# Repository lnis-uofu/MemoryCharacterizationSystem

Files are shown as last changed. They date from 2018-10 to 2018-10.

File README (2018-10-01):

 ¸,ø¤º°`°º¤ø,¸¸,ø¤º°  LNIS at University of Utah  °º¤ø,¸¸,ø¤º°`°º¤ø,¸
                   Prof. Pierre-Emmanuel Gaillardon
                  pierre-emmanuel.gaillardon@utah.edu

*--------------------------------------------------------------------------
* Memory Characterization System Development Package README
*--------------------------------------------------------------------------

* Readme File Author : Armando Biscontini
* Created On 	       : September 8, 2016
* Last Modified On   : September 8, 2016
* Description	       : This file describes the  directory structure
*                      of the MCS Development Package
*--------------------------------------------------------------------------

*** Disclaimer

This program is free software. It comes without any warranty, to
the extent permitted by applicable law. You can redistribute it
and/or modify it under the terms of the GNU Lesser General Public License, Version 3.
See https://www.gnu.org/licenses/lgpl-3.0.txt for more details.

If you use any of the material that comes along with this package, please refer to the
following paper for citation purpose:

A. Biscontini, M. Thammasack, G. De Micheli and P.-E. Gaillardon,
"An FPGA-Based Test System for RRAM Technology Characterization"

*** MCS Dev Package Directory Structure

▾ MCS_dev_package/

  ▾  PCB/						    : Contains the files regarding the MCS printed circuit board design.
    
    ▸ Datasheets/ 			: Folder containing the datasheets of the component that are mounted on the PCB.
    
    ▸ ReRAM Libraries/  : Altium design libraries necessary for a complete dasgn of the MCS. 
    
    ▸ ReRAM_Board_3/    : Altium design project folder.
  
  ▾ chip_and_custom_socket_3DCAD/

    ▸ LSI-PLLGA100_0.9.4/        : Folder containing the SolidWorks CAD files of the of the chip.

    ▸ LPF100-0691-15AB55L.PDF    : CAD drawing of the custom socket.

  ▾ chip_cadence_files       : Folder that holds all the Cadence design files of the chip.

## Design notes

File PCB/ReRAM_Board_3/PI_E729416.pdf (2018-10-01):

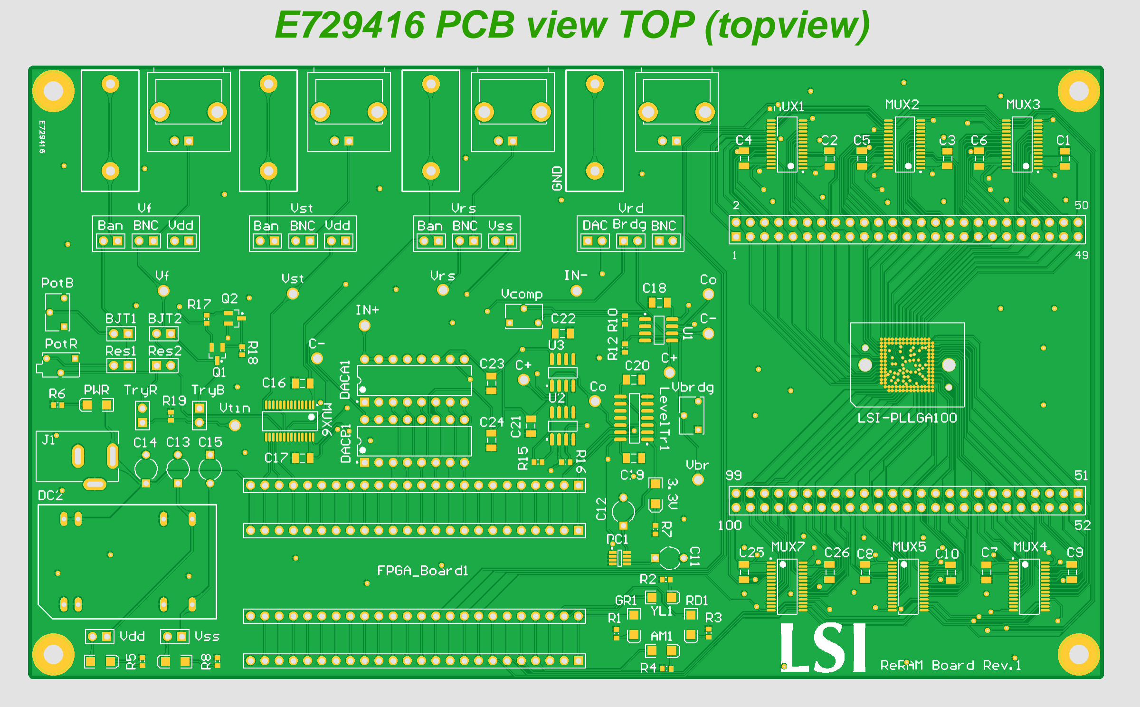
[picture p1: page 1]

E729416 PCB view TOP (topview)

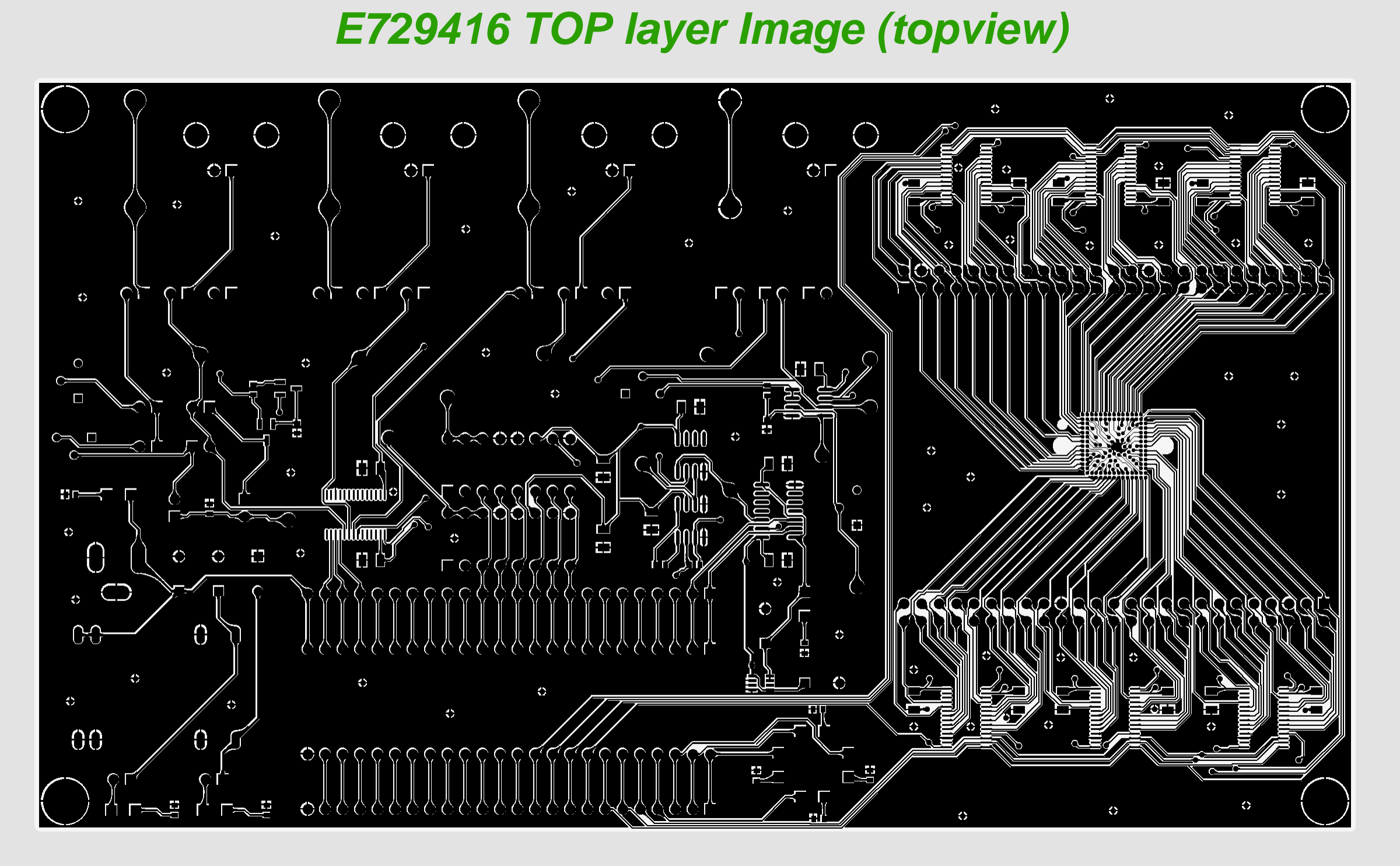
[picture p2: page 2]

E729416 TOP layer Image (topview)

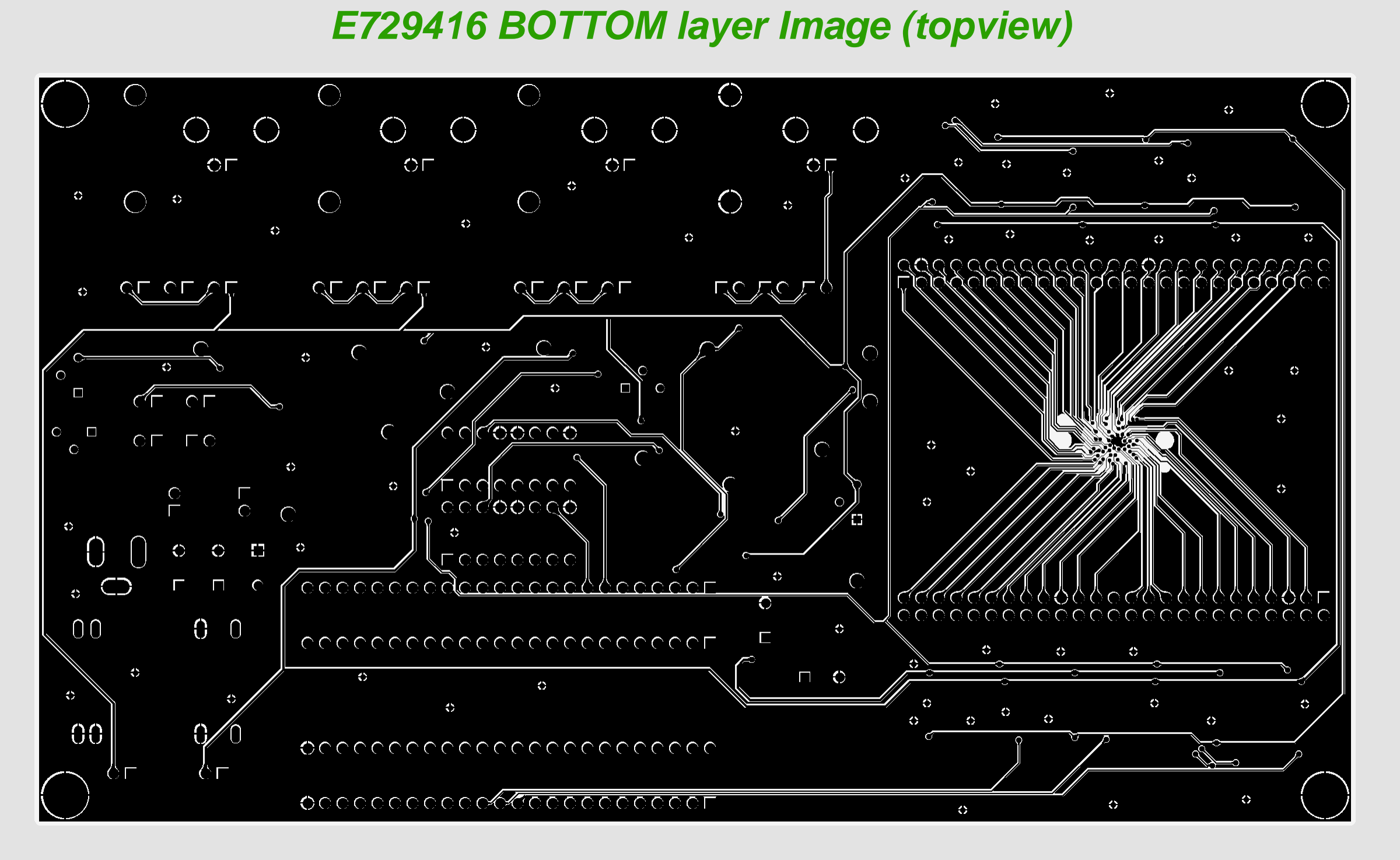
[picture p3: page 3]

E729416 BOTTOM layer Image (topview)

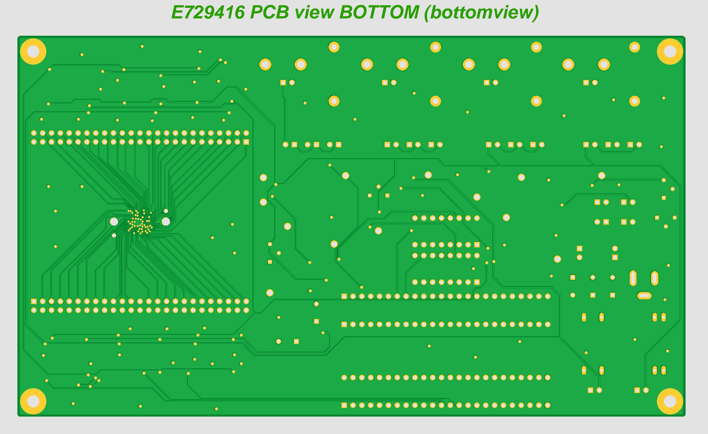
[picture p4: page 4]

E729416 PCB view BOTTOM (bottomview)

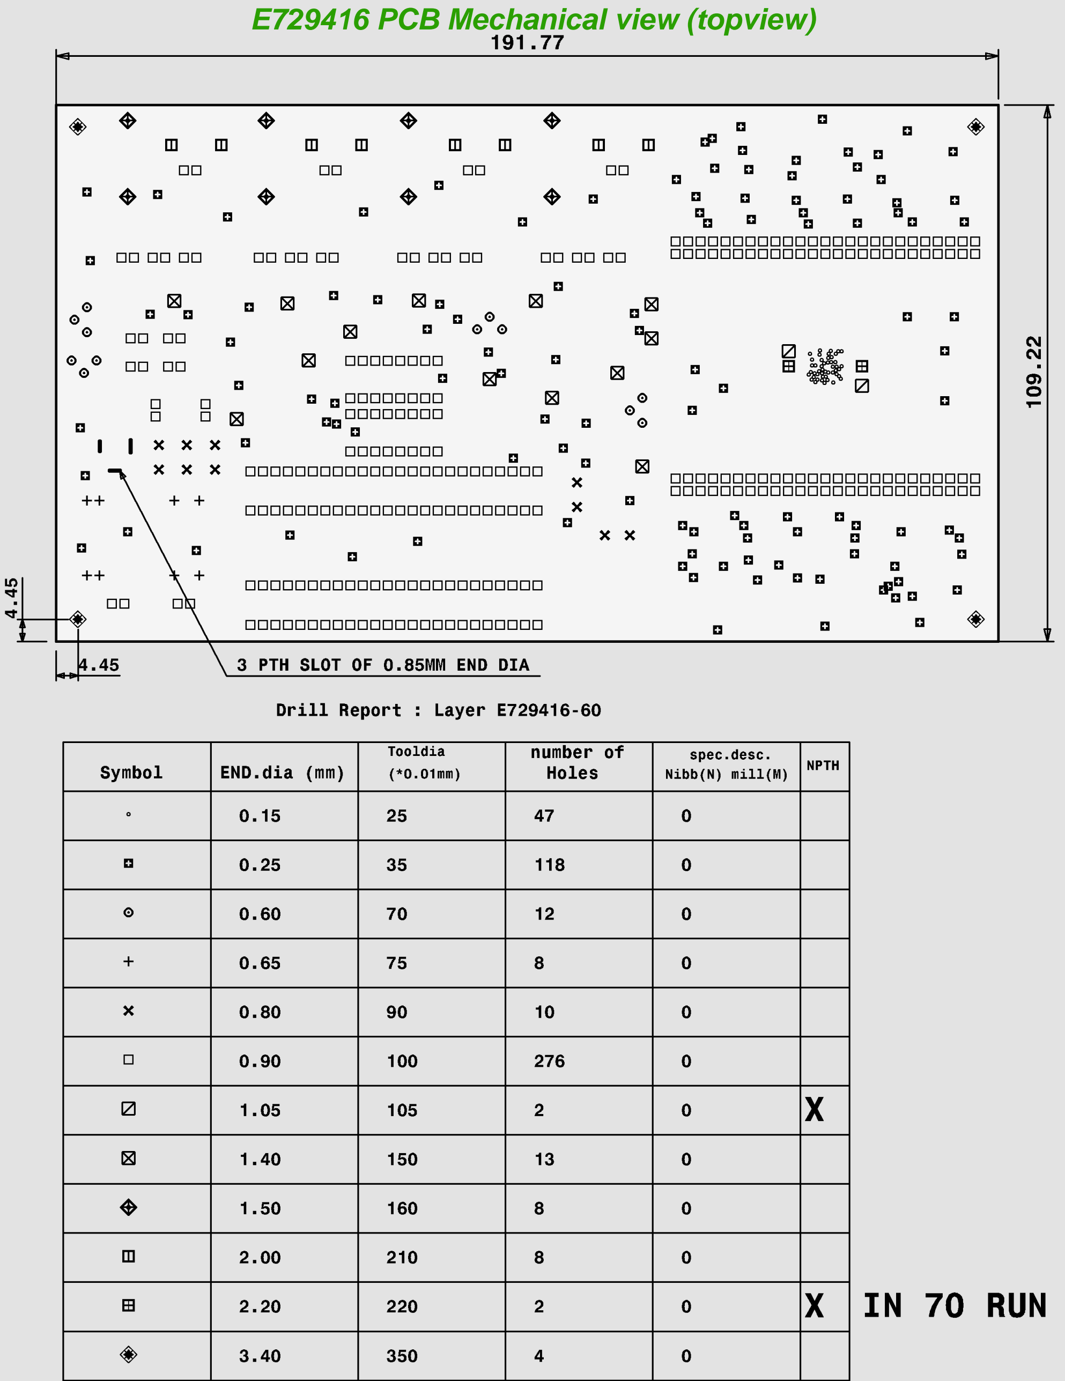
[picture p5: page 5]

E729416 PCB Mechanical view (topview)

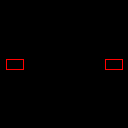
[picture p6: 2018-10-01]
chip_cadence_files/reram_library_rev4/FLECHE_2X1_10/layout/thumbnail_128x128.png

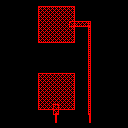
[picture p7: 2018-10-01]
chip_cadence_files/reram_library_rev4/dual_pad/layout/thumbnail_128x128.png

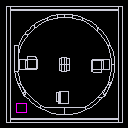
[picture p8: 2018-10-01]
chip_cadence_files/reram_library_rev4/MaskOutline/layout/thumbnail_128x128.png

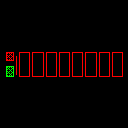
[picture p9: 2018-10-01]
chip_cadence_files/reram_library_rev4/pad_row/layout/thumbnail_128x128.png

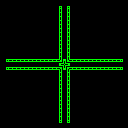
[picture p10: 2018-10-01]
chip_cadence_files/reram_library_rev4/DicingCross/layout/thumbnail_128x128.png

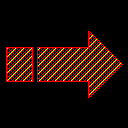
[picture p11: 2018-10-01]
chip_cadence_files/reram_library_rev4/FLECHE/layout/thumbnail_128x128.png

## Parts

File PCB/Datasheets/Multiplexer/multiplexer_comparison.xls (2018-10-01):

 | Item Name | Producer | Ron [Ohm] | Source Off Leakage [nA] | Drain Off Leakage [nA] | Channel On Leakage [nA] | T transition [ns] | -3dB BW [MHz] | Comment | Datasheet
1 | AD7506 | Analog Devices | 300 | 0.05 | 0.3 | 0.3 | 700 | undeclared |  | http://www.analog.com/media/en/technical-documentation/data-sheets/AD7506.pdf
2 | ADG426 | Analog Devices | 50 | 0.5 | 1 | 1 | 120 | undeclared |  | http://www.analog.com/media/en/technical-documentation/data-sheets/ADG406_407_426.pdf
3 | ADG506A | Analog Devices | 280 | 0.02 | 0.04 | 0.04 | 200 | undeclared |  | http://www.analog.com/media/en/technical-documentation/data-sheets/ADG506A_507A.pdf
4 | ADG526A | Analog Devices | 280 | 0.02 | 0.04 | 0.04 | 200 | undeclared |  | http://www.analog.com/media/en/technical-documentation/data-sheets/ADG526A_527A.pdf
5 | ADG706 | Analog Devices | 2.5 | 0.01 | 0.01 | 0.01 | 40 | 25 | Only -2.5V to +2.5V dynamic range! | http://www.analog.com/media/en/technical-documentation/data-sheets/ADG706_707.pdf
6 | ADG1206 | Analog Devices | 120 | 0.03 | 0.05 | 0.08 | 80 | 280 |  | http://www.analog.com/media/en/technical-documentation/data-sheets/ADG1206_1207.pdf
7 | ADG1406 | Analog Devices | 21 | 0.01 | 0.01 | 0.01 | 260 | 40 |  | http://www.analog.com/media/en/technical-documentation/data-sheets/ADG1406_1407.pdf
8 | ADG1606 | Analog Devices | 4.5 | 0.02 | 0.05 | 0.1 | 175 | 21 |  | http://www.analog.com/media/en/technical-documentation/data-sheets/ADG1606_1607.pdf
9 | ADG5206 | Analog Devices | 155 | 0.005 | 0.02 | 0.02 | 200 | 60 |  | http://www.analog.com/media/en/technical-documentation/data-sheets/ADG5206_5207.pdf
10 | DG406 | Vishay | 50 | 0.01 | 0.04 | 0.04 | 200 | undeclared |  | http://www.vishay.com/docs/70061/dg406.pdf
11 | DG406 | Maxim | 60 | 0.01 | 0.02 | 0.02 | 110 | undeclared |  | http://datasheets.maximintegrated.com/en/ds/DG406-DG407.pdf
12 | DG506A | Maxim | 270 | 0.002 | 0.02 | 0.03 | 600 | undeclared |  | http://datasheets.maximintegrated.com/en/ds/DG506A-DG507A.pdf
13 | MAX306 | Maxim | 60 | 0.01 | 0.02 | 0.02 | 110 | undeclared |  | http://datasheets.maximintegrated.com/en/ds/MAX306-MAX307.pdf
14 | MAX336 | Maxim | 220 | 0.02 | 0.05 | 0.05 | 200 | undeclared |  | http://datasheets.maximintegrated.com/en/ds/MAX336-MAX337.pdf
15 | MAX396 | Maxim | 60 | 0.03 | 0.05 | 0.09 | 95 | undeclared |  | http://datasheets.maximintegrated.com/en/ds/MAX396-MAX397.pdf
16 | CD4067B | Texas Instruments | 470 | 0.1 |  | undeclared | undeclared | 14 |  | http://www.ti.com/lit/ds/symlink/cd4097b.pdf
17 | MPC506A | Burr-Brown | 1300 | 0.5 | 0.2 | 2 | 300 | undeclared |  | http://www.ti.com.cn/cn/lit/ds/symlink/mpc507.pdf
18 | ADG731 | Analog Devices | 4 | 0.01 | 0.05 | 0.01 | 55 | 18 | Only -2.5V to +2.5V dynamic range! | http://www.analog.com/media/en/technical-documentation/data-sheets/ADG725_731.pdf
19 | ADG732 | Analog Devices | 4 | 0.01 | 0.05 | 0.05 | 33 | 18 | Only -2.5V to +2.5V dynamic range! | http://www.analog.com/media/en/technical-documentation/data-sheets/ADG726_732.pdf
 |  | All data evaluated at: dual supply, typical, @25°C
 | MUX 16ch
 | MUX 32ch

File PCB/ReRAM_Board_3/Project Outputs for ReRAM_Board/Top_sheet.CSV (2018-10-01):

Bill of Material for
On 19.06.2015 at 11:48:37
Comment | Pattern | Quantity | Components
 | 3.2X1.6X1.1 | 4 | GR2, GR3, GR4, RD2 | Typical RED, GREEN, YELLOW, AMBER GaAs LED
AD558JNZ | N-16 | 2 | DACA1, DACB1 | Single 8-Bit Low Cost Complete uP-Compatible DACPORT, 0 to +70 degC, N-16, Pb-Free, Tube
AD8616ARZ | ADI-R-8_N | 2 | U1, U3 | Double Channel Wide Bandwidth Operational Amplifier, 24 MHz BW, 12 V/us SR, Industrial, 8-pin SOIC (R-8), Tube
ADG1606 | TSOP65P640X120-28N | 7 | MUX1, MUX2, MUX3, MUX4, MUX5, MUX6, MUX7 | Analog Devices ADG1606
Banana_conn | Banana_conn_4mm | 4 | B1, B2, B3, B4 | Multicomp banana connector 4mm pcb through hole
BNC | BNC_RA CON | 4 | BNC1, BNC2, BNC3, BNC4 | BNC Elbow Connector
BSS84_MOSFET-P | BSS84_MOSFET-P | 1 | Q1 | BSS84 P-Channel MOSFET
Cap Semi | C1206 | 21 | C1, C2, C3, C4, C5, C6, C7, C8, C9, C10, C16, C17, C18, C19, C20, C21, C22, C23, C24, C25, C26 | Capacitor (Semiconductor SIM Model)
Cap2 | CAPR5-4X5 | 5 | C11, C12, C13, C14, C15 | Capacitor
Cmod_S6 | Cmod_S6_double_conn | 1 | FPGA_Board1 | Digilent Cmod S6 Board
Header 2 | HDR1X2 | 20 | P3, P4, P5, P6, P7, P8, P9, P10, P11, P12, P13, P14, P15, P16, P17, P18, P19, P20, P21, P22 | Header, 2-Pin
Header 24 | HDR1X24 | 2 | P1, P2 | Header, 24-Pin
Header 25X2 | HDR2X25 | 2 | P23, P24 | Header, 25-Pin, Dual row
LED2 | 3.2X1.6X1.1 | 4 | AM1, GR1, RD1, YL1 | Typical RED, GREEN, YELLOW, AMBER GaAs LED
LT1167AIS8#PBF | LT-S8-8_N | 1 | U2 | Single Channel, Precision Operational Amplifier, Low Bias Current IA, 1 MHz Typical GBW, 1.2 V/us Typical SR, 4.6 to 40 V, 8-Pin SOIC (S8-8), Industrial, Pb-Free
LT3007ETS8-3.3#TRMPBF | LT-TS8-8-TSOT-23_V | 1 | DC1 | 3 uA IQ, 20 mA, Low Dropout Fault Tolerant Linear Regulator, 2 to 45 V Vin, 3.3 V Vout, 8-pin SOT23 (TS8-8), -40 to 125 degC, Pb-Free, Mini Tape and Reel
M3_hole | M3_hole | 4 | H1, H2, H3, H4 | M3 hole
PNP | MMBT5087_PNP | 1 | Q2 | MMBT5087 PNP Bipolar Transistor
PWR2.5 | KLD-0202 | 1 | J1 | Low Voltage Power Supply Connector
ReRAM chip | LSI-PLLGA100 | 1 | RR1 | ReRAM chip on LSI-PLLGA100 custom socket
Res3 | J1-0603 | 15 | R1, R2, R3, R4, R5, R6, R7, R8, R10, R12, R15, R16, R17, R18, R19 | Resistor
TEN_3-1221 | TEN_3-1221 | 1 | DC2 | Tracopower TEN 3-1221
Test_point | Test_point_1.32mm | 13 | T1, T2, T3, T4, T5, T6, T7, T8, T9, T10, T11, T12, T13 | Test point 1.32mm
Trim | Trim_Bourns_3266W | 3 | R11, R13, R14 | Trimmer Bourns 3266W
Trim | Trim_Bourns_3266X | 1 | R9 | Trimmer Bourns 3266X
TXS0104E | SOIC127P600X175-14N | 1 | LevelTr1 | Texas Instruments TXS0104E

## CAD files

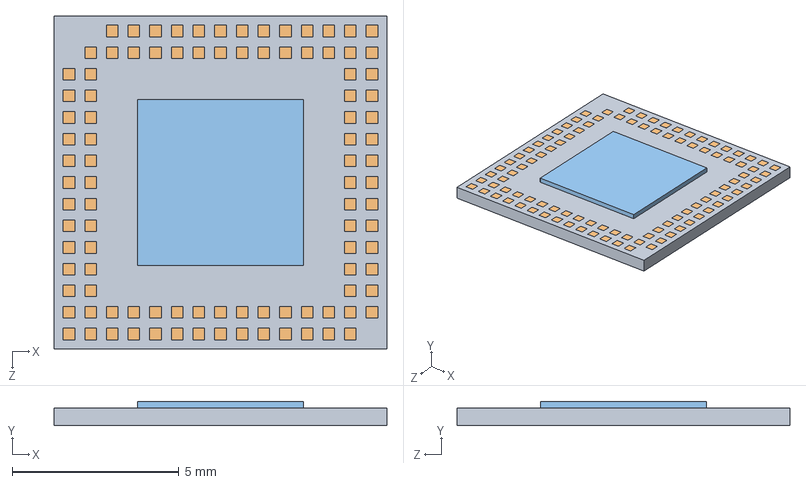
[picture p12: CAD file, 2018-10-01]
chip_and_custom_socket_3DCAD/LSI-PLLGA100_0.9.4/LSI-PLLGA100.SLDASM
10.0 x 0.725 x 10.0 mm
wafer
add_chip

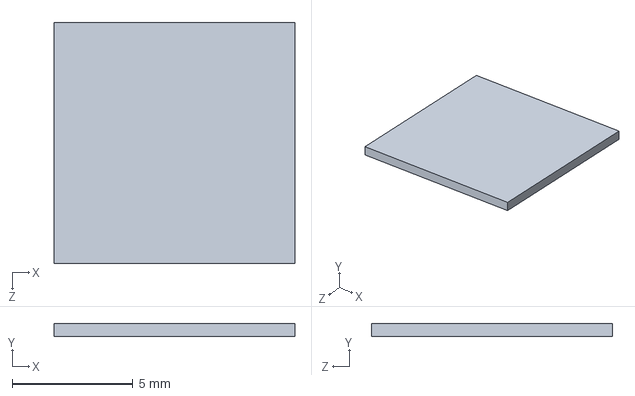
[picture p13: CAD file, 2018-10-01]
chip_and_custom_socket_3DCAD/LSI-PLLGA100_0.9.4/wafer.SLDPRT
10.0 x 0.525 x 10.0 mm

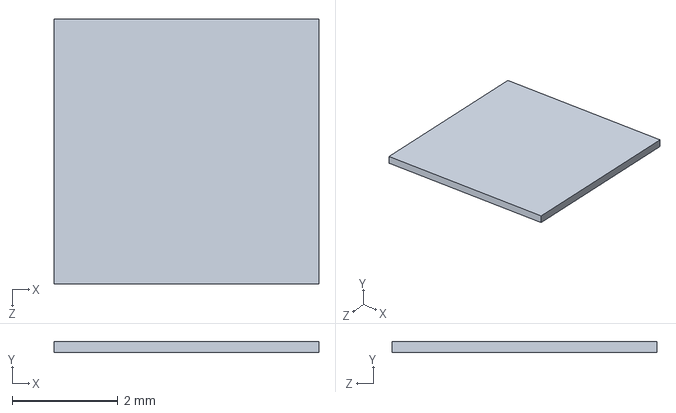
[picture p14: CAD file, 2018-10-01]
chip_and_custom_socket_3DCAD/LSI-PLLGA100_0.9.4/add_chip.SLDPRT
5.00 x 0.2 x 5.00 mm

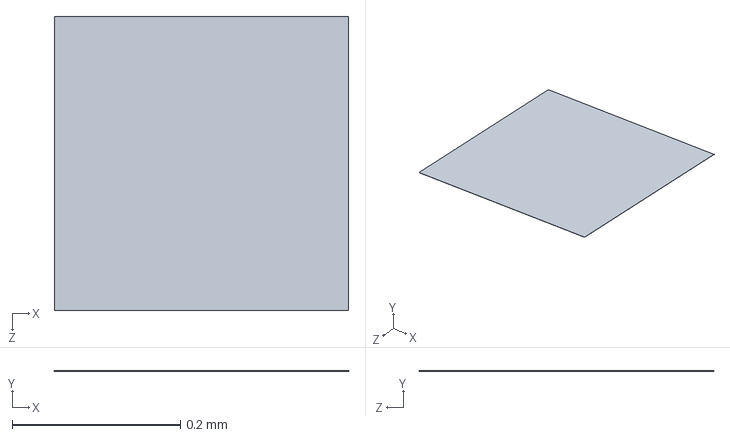
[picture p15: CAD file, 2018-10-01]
chip_and_custom_socket_3DCAD/LSI-PLLGA100_0.9.4/pad.SLDPRT
0.35 x 0.0003 x 0.35 mm

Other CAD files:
chip_and_custom_socket_3DCAD/LSI-PLLGA100_0.9.4/LSI-PLLGA100.SLDDRW

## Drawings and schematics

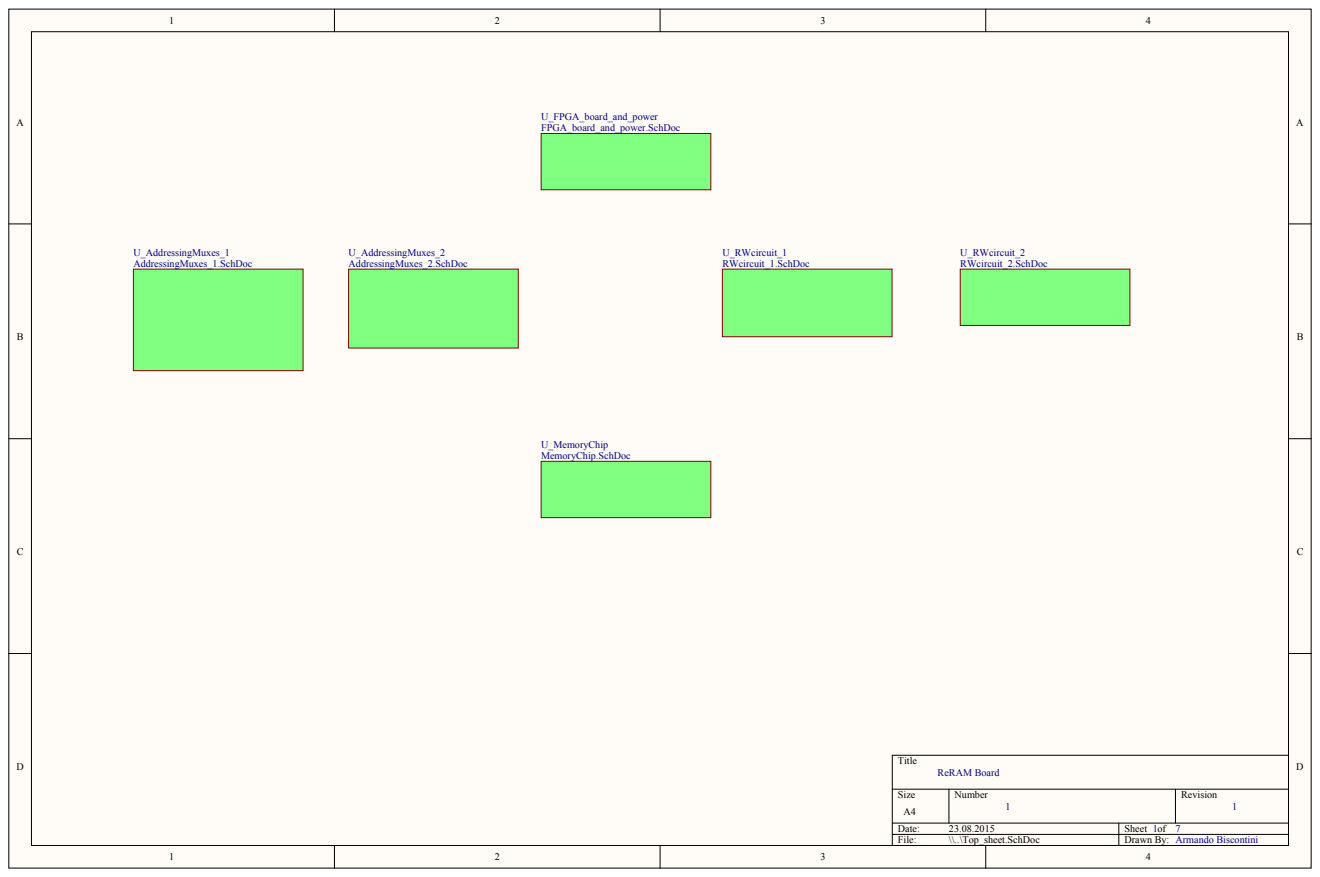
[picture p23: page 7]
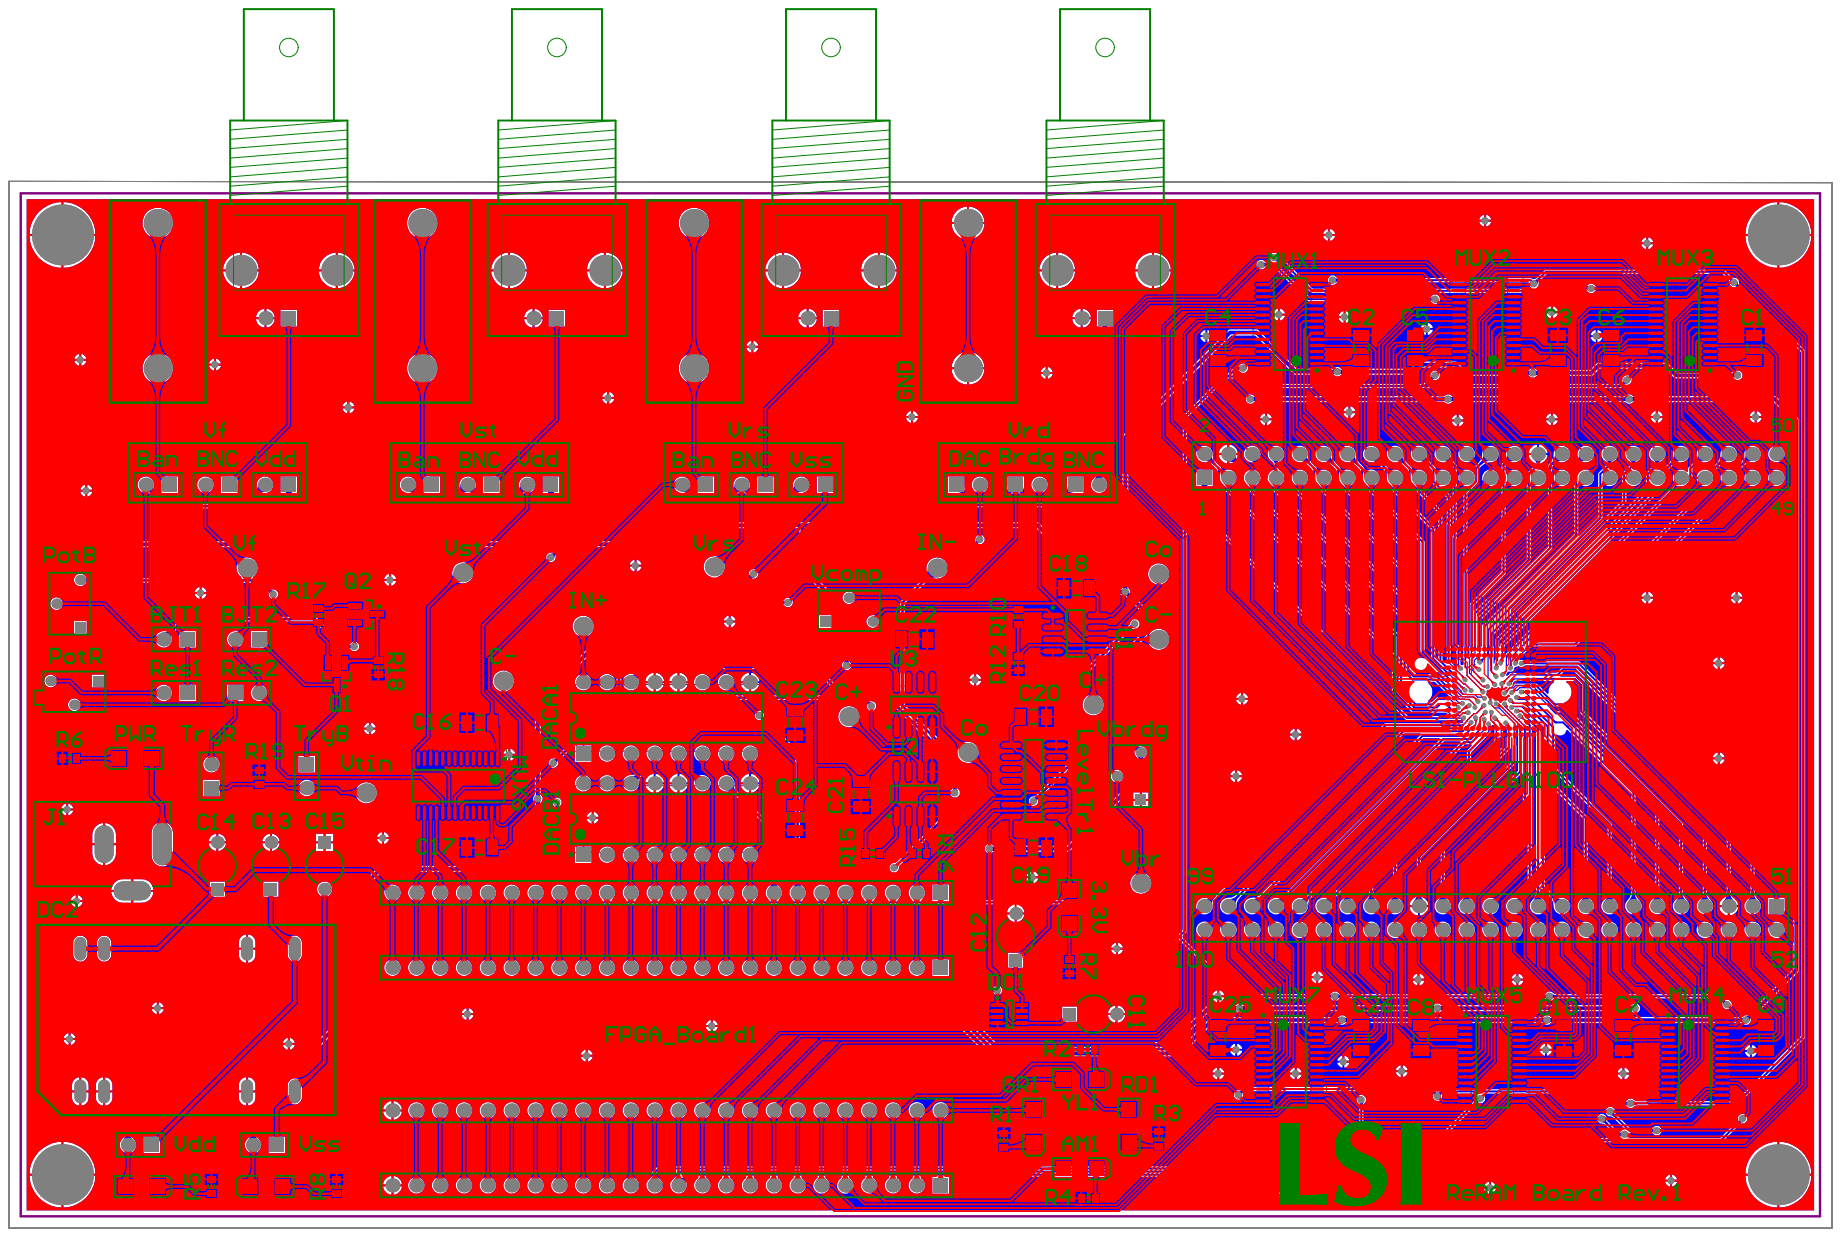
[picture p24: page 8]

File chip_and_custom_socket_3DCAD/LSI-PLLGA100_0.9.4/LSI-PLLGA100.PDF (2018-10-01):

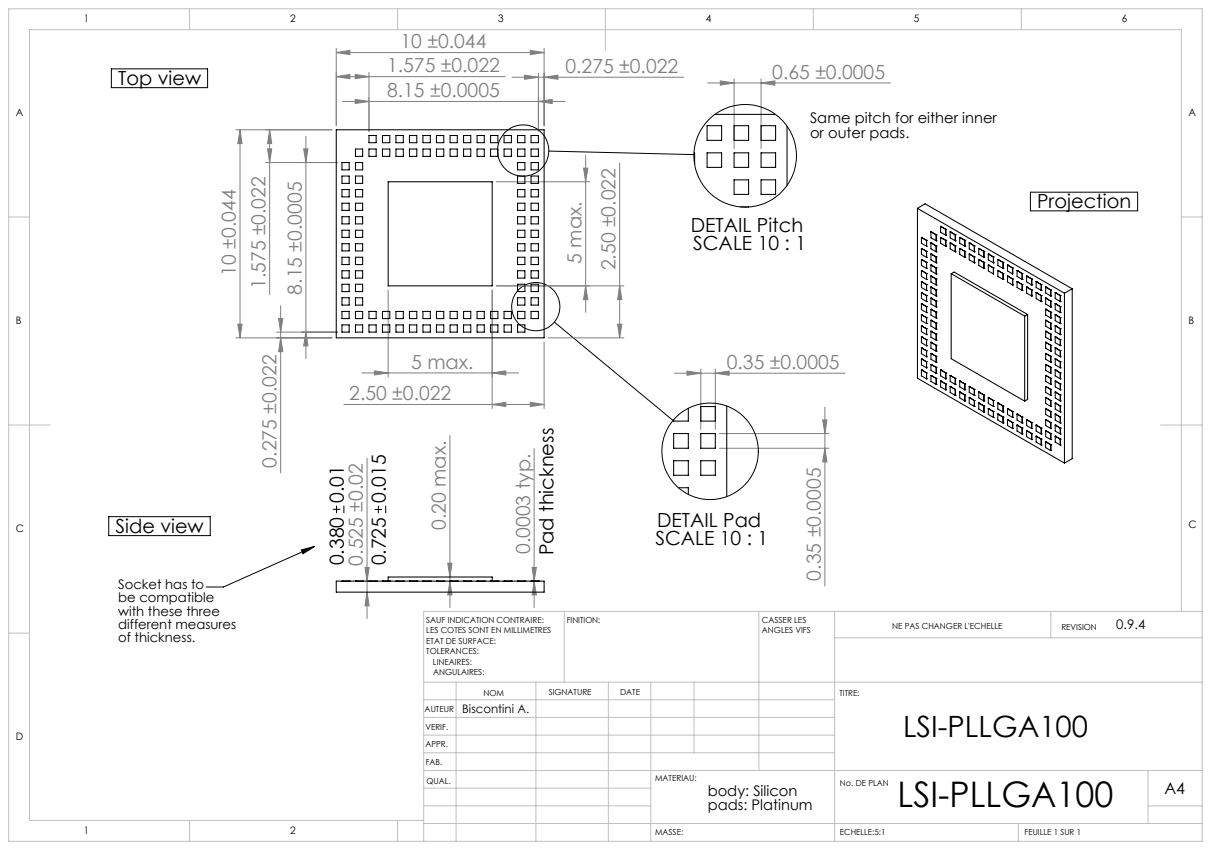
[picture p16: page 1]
0.20 max.; 0.0003 typ.; 5 max.; DETAIL Pad SCALE 10 : 1; DETAIL Pitch SCALE 10 : 1; Side view; Top view; Pad thickness; FINITION:; CASSER LES; ANGLES VIFS; NE PAS CHANGER L'ECHELLE; REVISION; ECHELLE:5:1; FEUILLE 1 SUR 1

10 ±0.044
1.575 ±0.022

Same pitch for either inner
or outer pads.

Socket has to
be compatible
with these three
different measures
of thickness.

SAUF INDICATION CONTRAIRE:
LES COTES SONT EN MILLIMETRES
ETAT DE SURFACE:
TOLERANCES:
LINEAIRES:
ANGULAIRES:

NOM | SIGNATURE | DATE | | | | TITRE: LSI-PLLGA100

AUTEUR | Biscontini A.
VERIF.
APPR.
FAB.
QUAL. | | | | MATERIAU: body: Silicon pads: Platinum | LSI-PLLGA100 No. DE PLAN | A4

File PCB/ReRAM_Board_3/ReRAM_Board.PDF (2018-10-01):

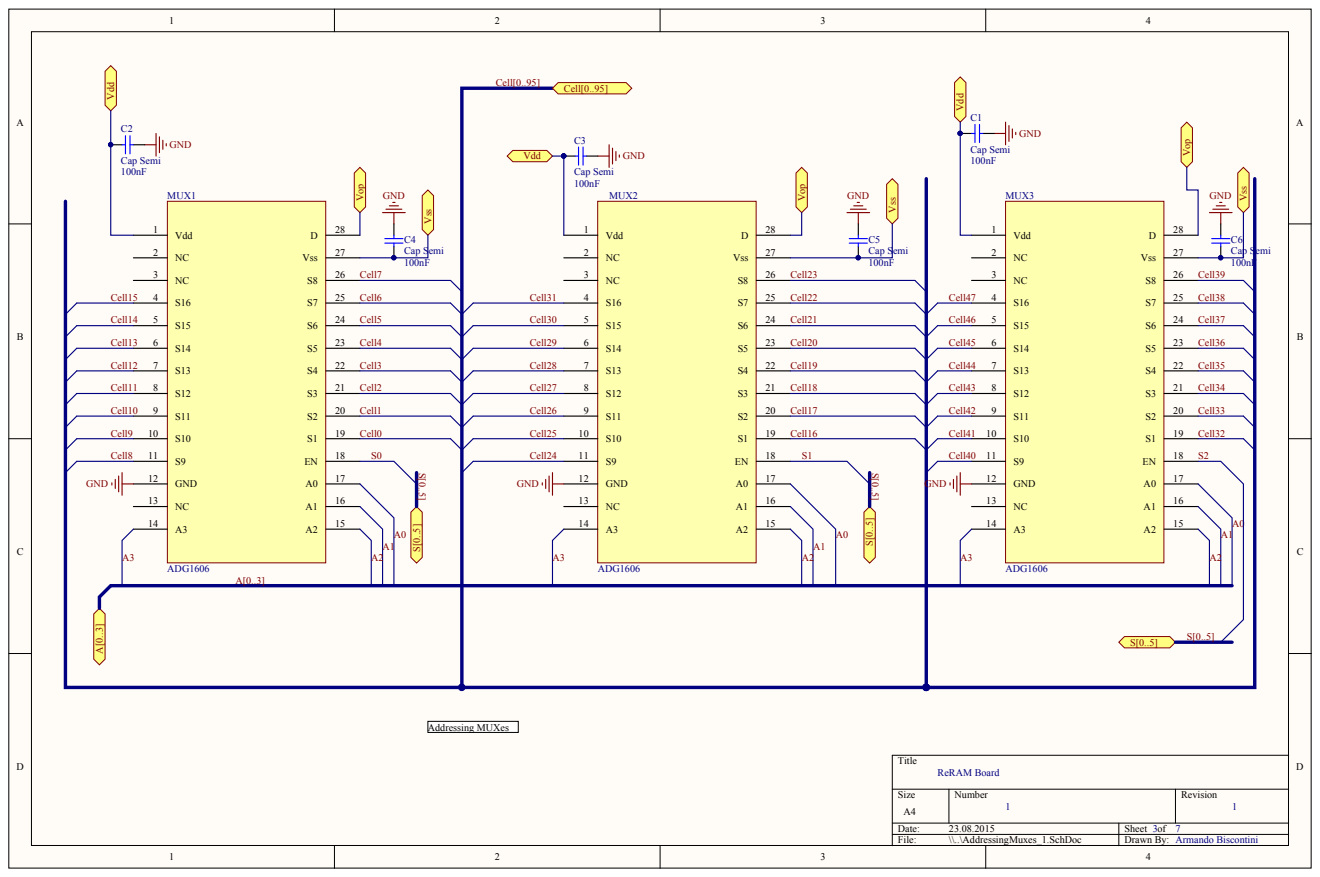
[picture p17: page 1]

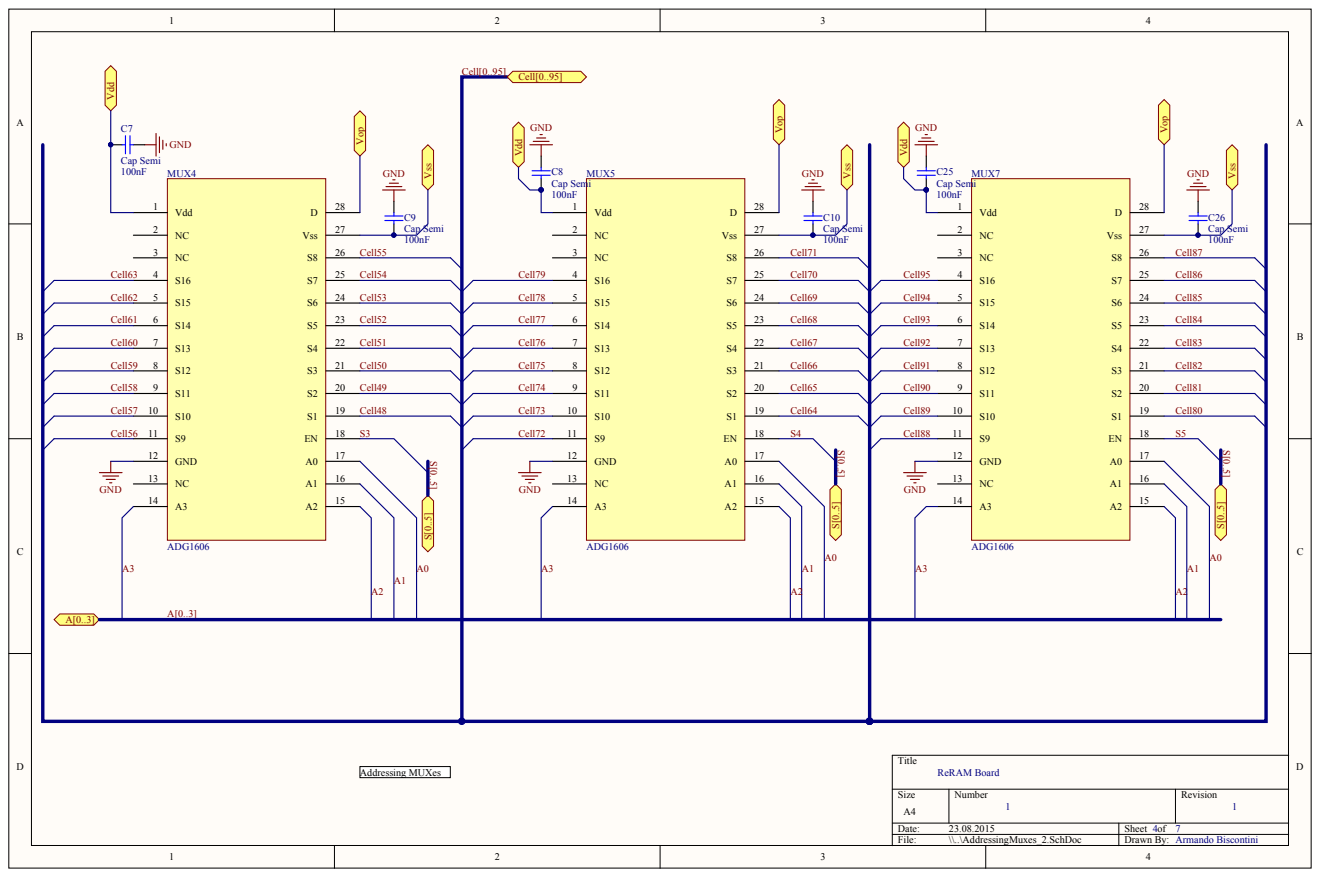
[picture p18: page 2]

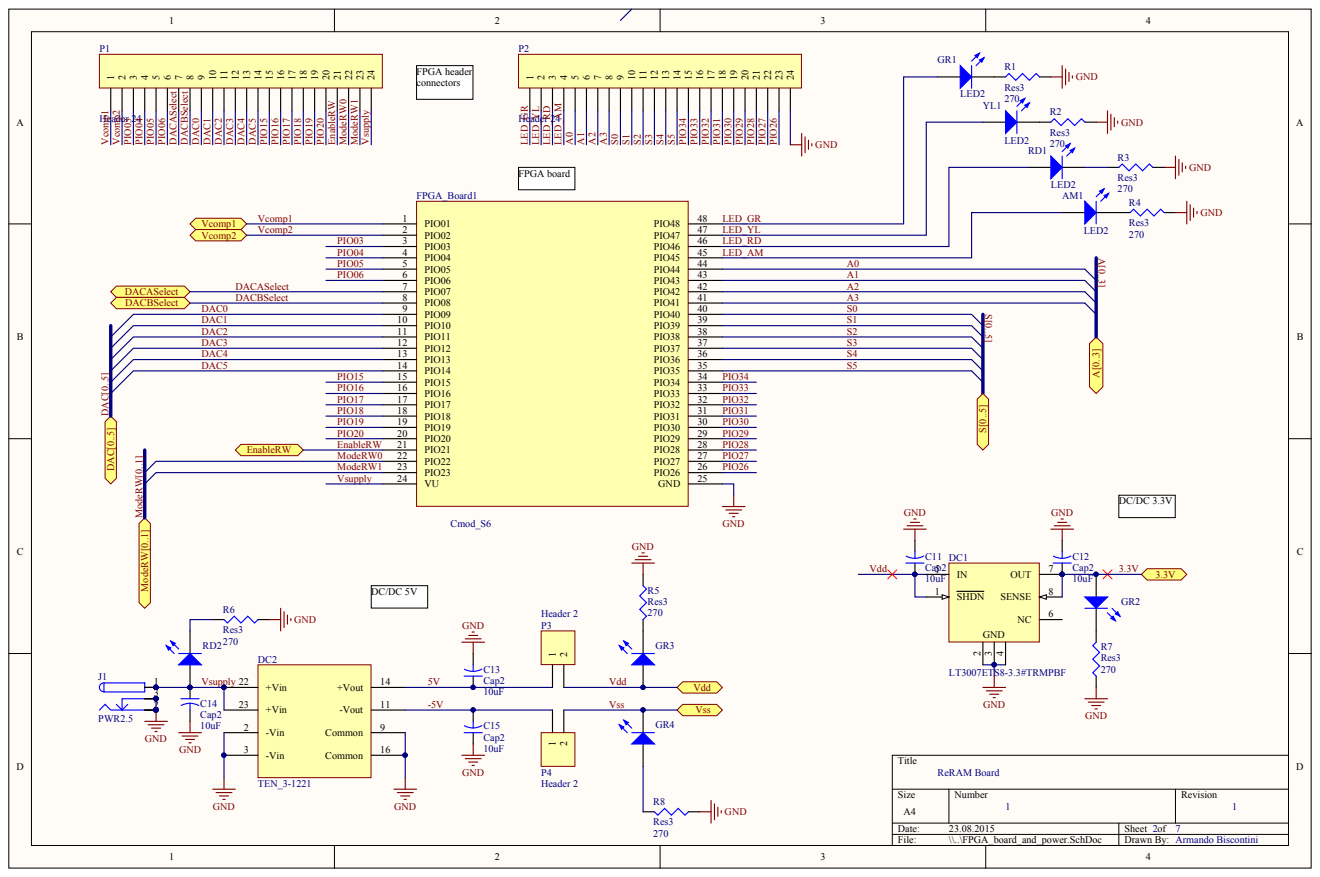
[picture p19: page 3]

LED_GR

PIO02 2 | LED_YL
PIO03 3 | LED_RD
PIO04 4 | LED_AM

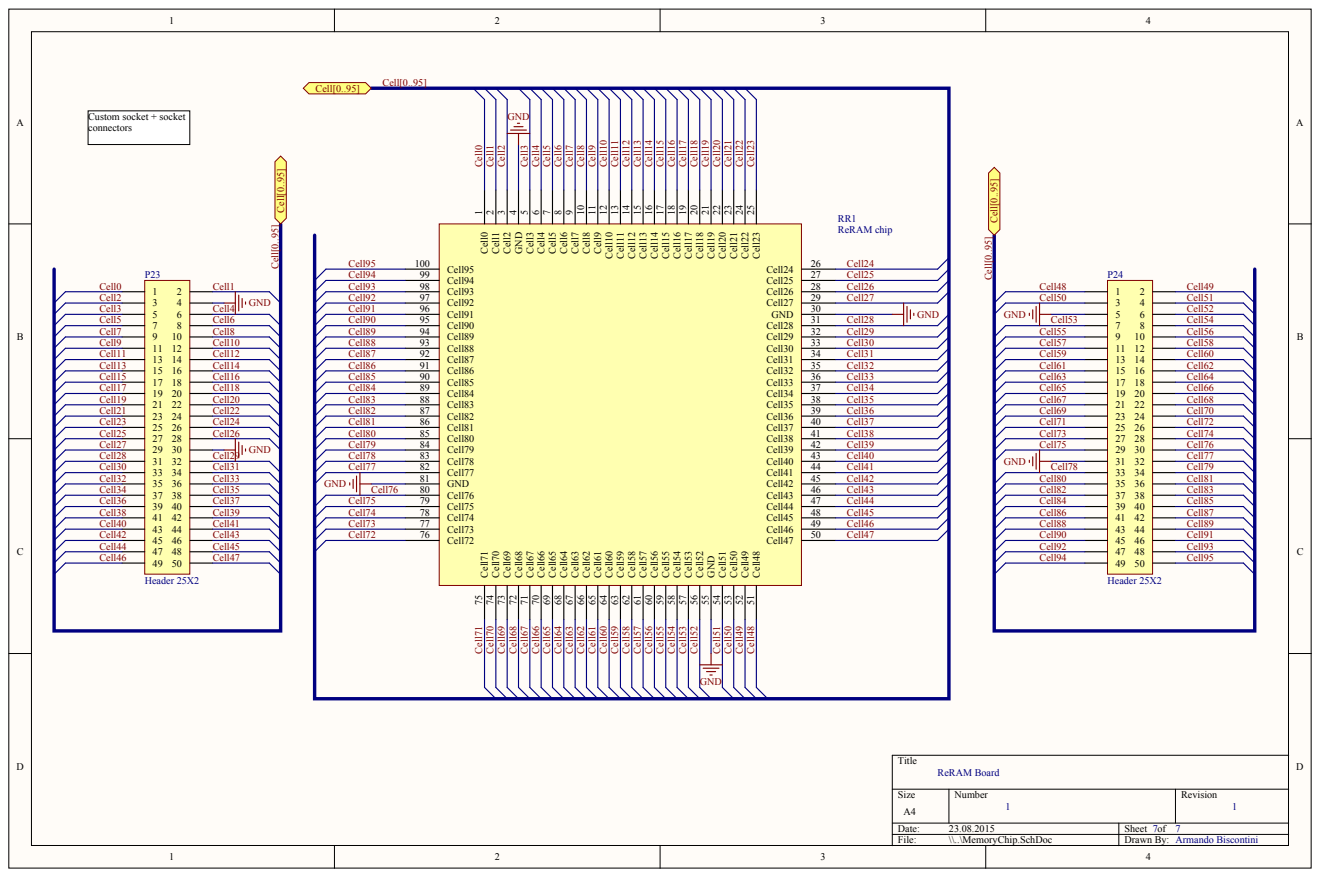
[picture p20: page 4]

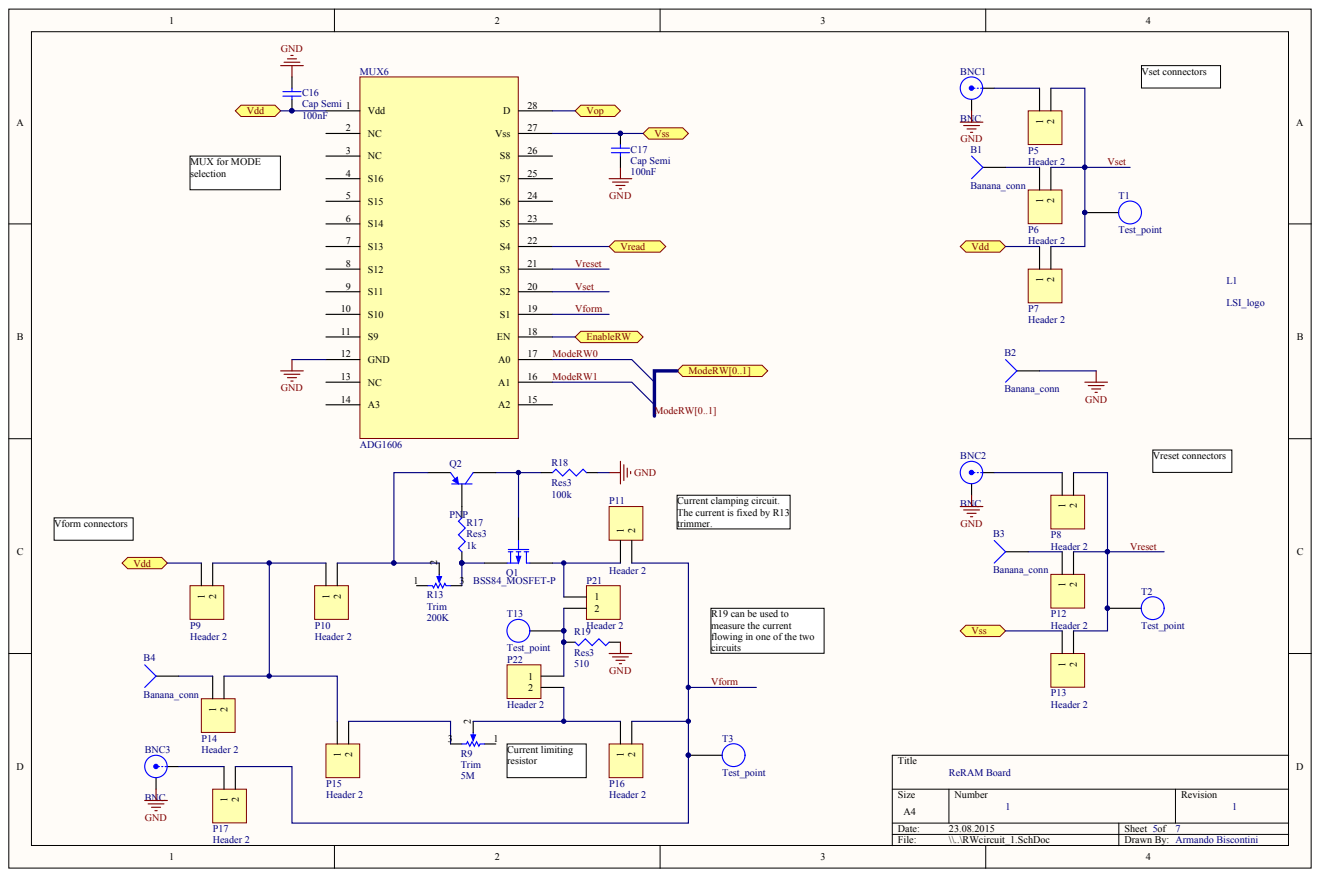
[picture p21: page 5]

Current clamping circuit.
The current is fixed by R13
trimmer.

R19 can be used to
measure the current
flowing in one of the two
circuits

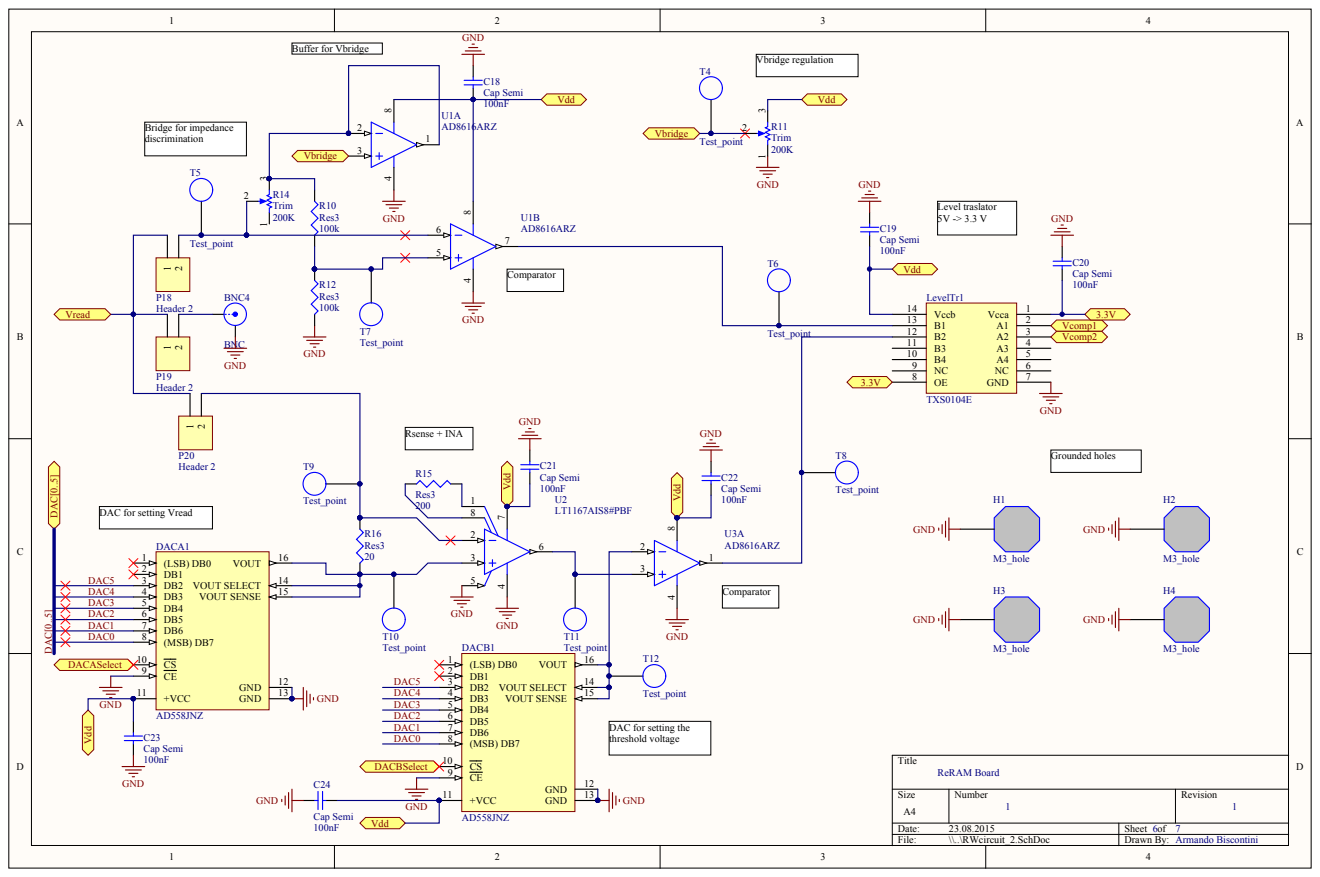
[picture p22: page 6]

DAC for setting Vread

DAC3 | DB4 5 | | GND
DAC2 | DB5 6 | GND

DAC for setting the
threshold voltage
